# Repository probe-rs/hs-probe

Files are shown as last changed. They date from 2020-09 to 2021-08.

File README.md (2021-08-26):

# The Rusty High-speed Probe

This is an open hardware probe for the Serial Wire Debug (SWD) and JTAG protocol. It utilizes an
STM32F723 MCU which has an USB 2.0 High-speed Phy.

## Firmware

The firmware is available here and is open-source: https://github.com/probe-rs/hs-probe-firmware

## Features

There is an USB MUX on the board, so when the probe starts it enumerates in USB FS where one can
access the internal bootloader, and then when the firmware takes over it can switch to the USB HS.

* The output connector can either be:
    * The STDC14 connector used on STLink/V3 which is mounted by default.
    * Or the standard Cortex-M Debug (1.27mm, 10 pin) connector if one bends/removes the outer 2 pins on the connector.
* The programming connector is the Tag Connect TC2030, however for just loading firmware the USB bootloader is recommended.
* USB is muxed between USB HS/FS.
* Castellated vias for all programming pins, power and 2 GPIOs.
* USB-C connector.
* Target 5V and 3.3V is protected with an ideal diode circuit to not have current flow from the target to the host.
* For compatibility (mainly with Tag-Connect TC2050), pin 7 on the STDC 14 can be connected to the protected 5V.

The schematic can be found in [the schematic PDF](schematic-v1.4.pdf).

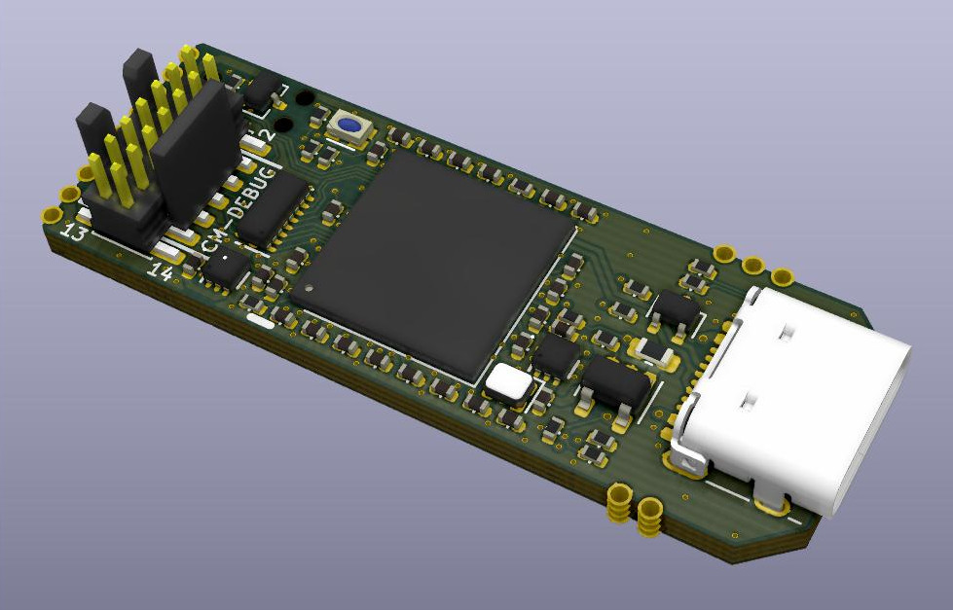
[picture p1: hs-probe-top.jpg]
probe

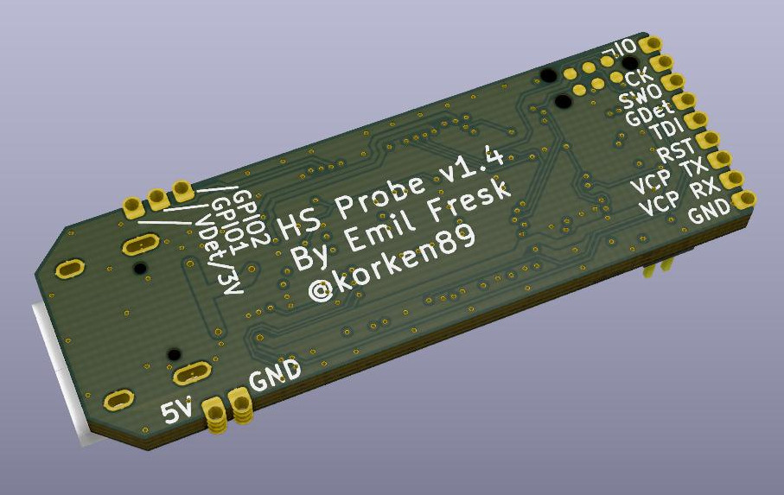
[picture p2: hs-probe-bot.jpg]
probe


## Cable Assembly

The hs-probe package sold on our [shop](https://shop.probe.rs) contains two 16 wire ribbon cables, three 14p connectors and one 10p connector.
You can make one cable with a 14p connector on each side and one cable with a 14p connector on one and a 10p connector on the other side. How to align the connectors is explained in the image below:

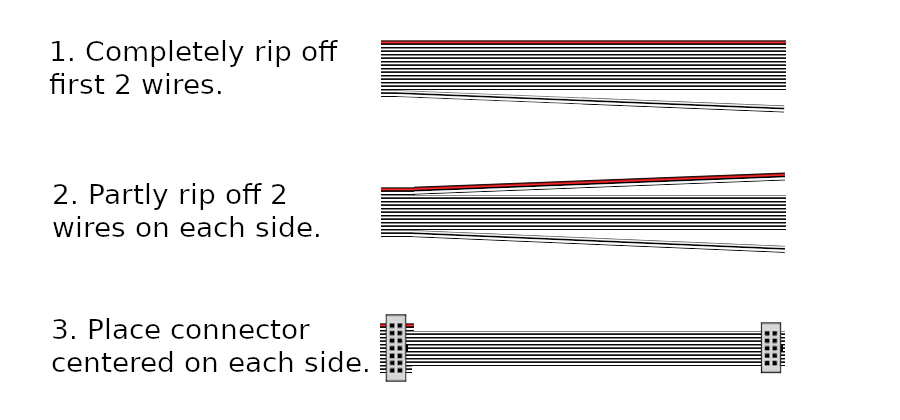
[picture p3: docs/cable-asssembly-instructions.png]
cable assembly


## License

This work is licensed under [CERN-OHL-P](cern_ohl_p_v2.txt).

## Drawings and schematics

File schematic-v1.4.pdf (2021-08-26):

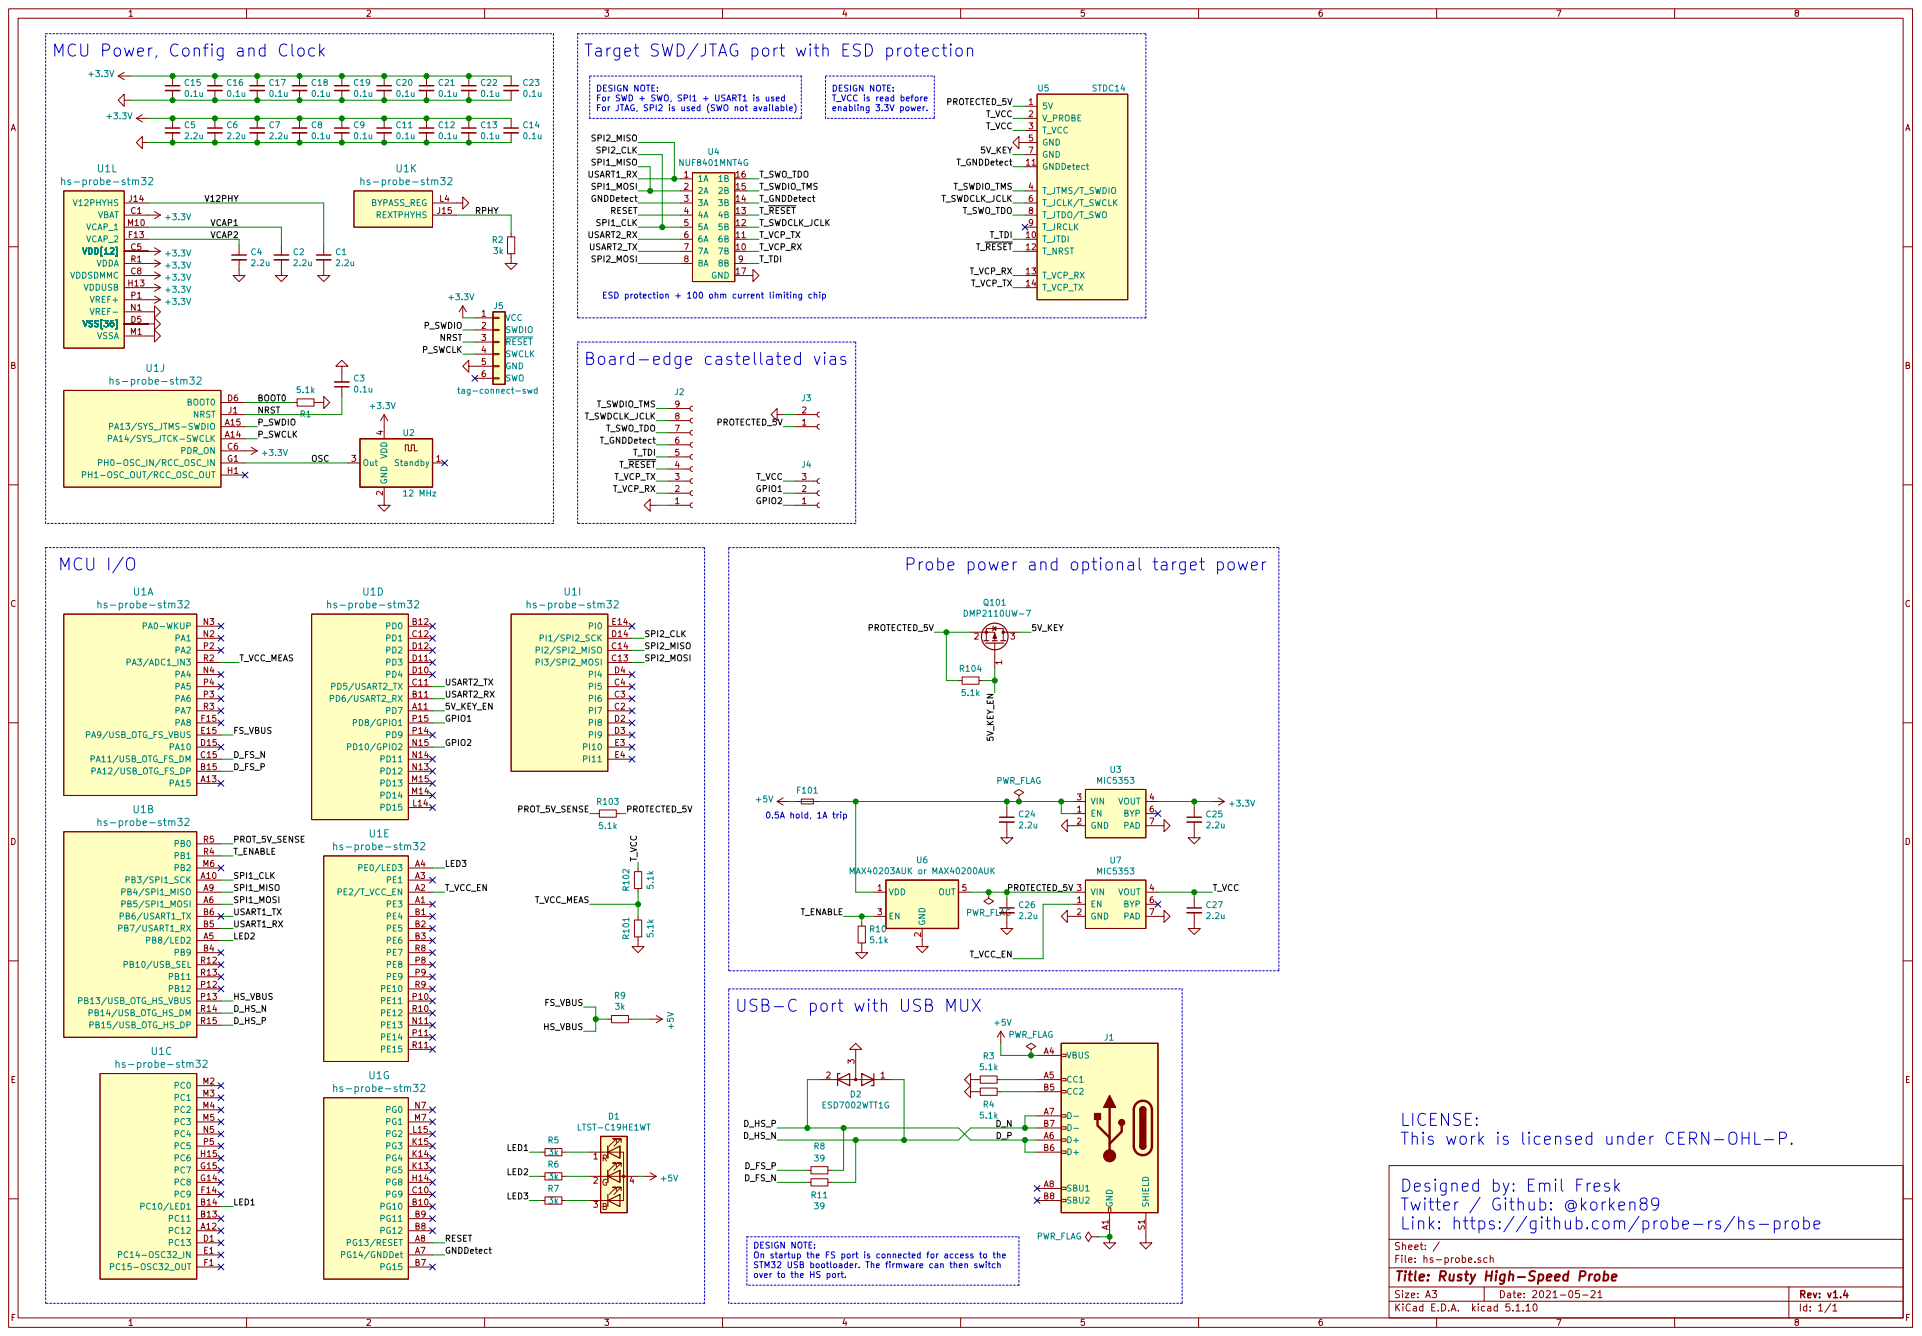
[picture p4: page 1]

MCU Power, Config and Clock

Target SWD/JTAG port with ESD protection

DESIGN NOTE: For SWD + SWO, SPI1 + USART1 is used For JTAG, SPI2 is used (SWO not available)

ESD protection + 100 ohm current limiting chip

Board-edge castellated vias

USB-C port with USB MUX

LICENSE:
This work is licensed under CERN-OHL-P.

Designed by: Emil Fresk
Twitter / Github: @korken89
Link: https://github.com/probe-rs/hs-probe

DESIGN NOTE: On startup the FS port is connected for access to the STM32 USB bootloader. The firmware can then switch over to the HS port.

File: hs-probe.sch Sheet: /
Id: 1/1 Title: Rusty High-Speed Probe

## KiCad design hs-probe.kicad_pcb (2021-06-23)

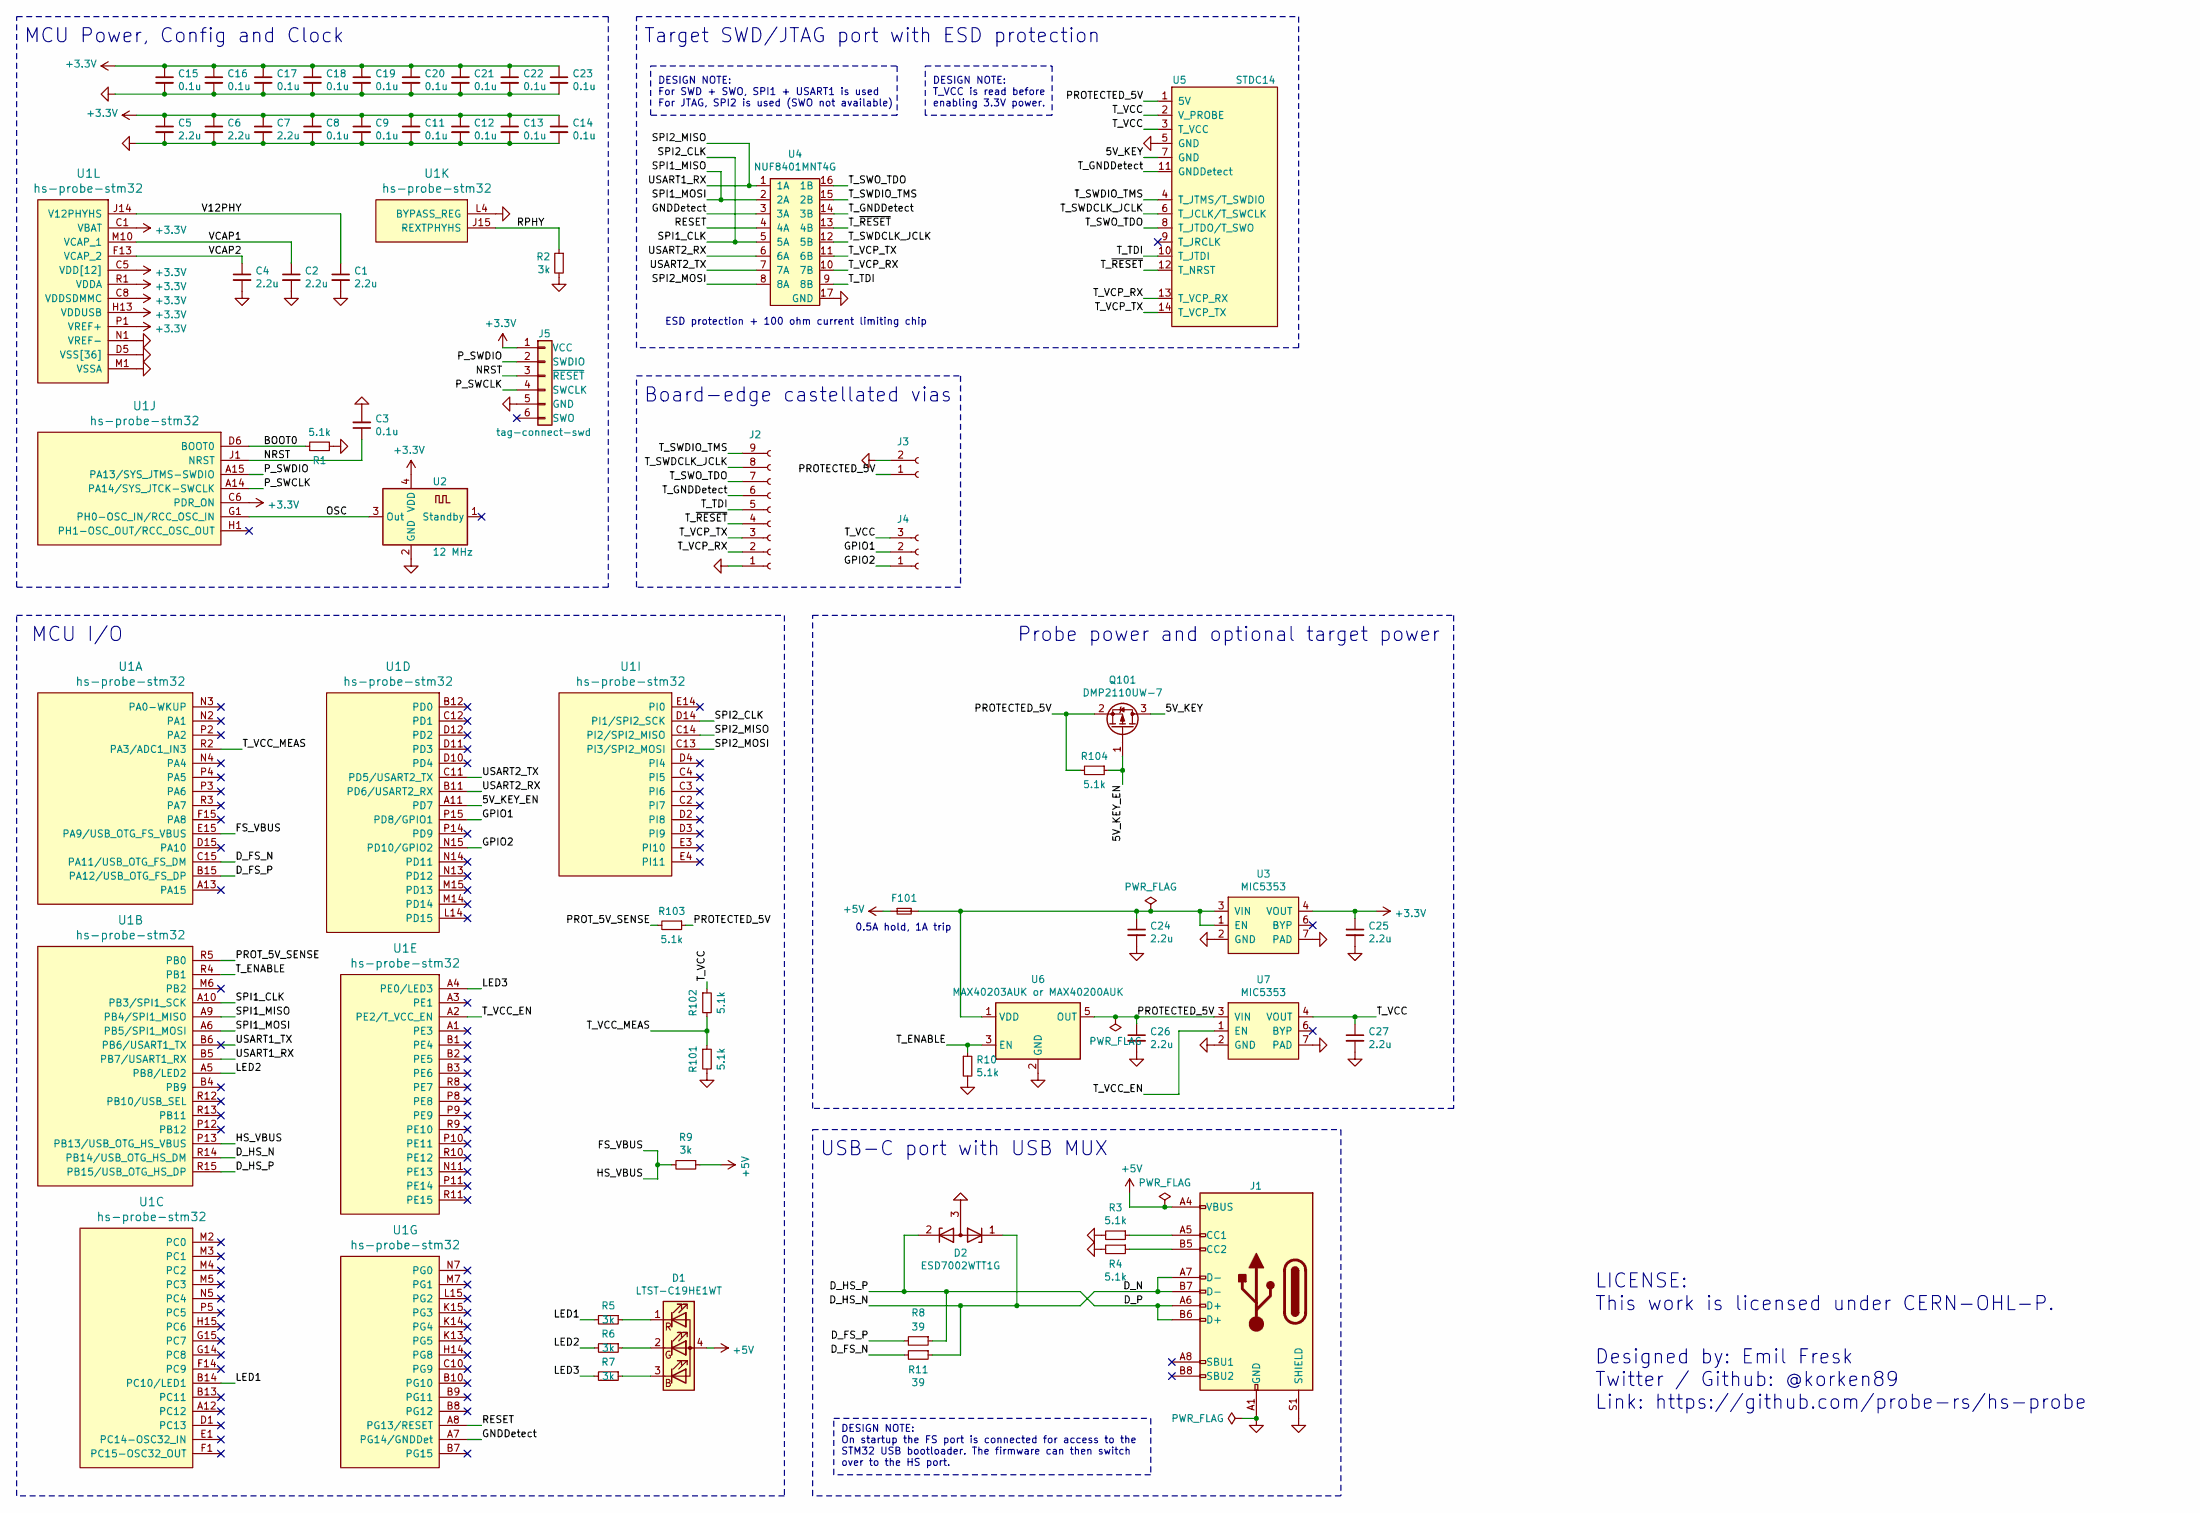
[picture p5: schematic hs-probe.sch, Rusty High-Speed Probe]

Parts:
C1, C2, C4, C5, C6, C7, C24, C25, C26, C27: 2.2u; C_0402; Tolerance 10V, X5R
C3, C8, C9, C11, C12, C13, C14, C15, C16, C17, C18, C19, C20, C21, C22, C23: 0.1u; C_0402; Tolerance 25V, X7R
D1: LTST-C19HE1WT; LED_LiteOn_LTST-C19HE1WT; MPN LTST-C19HE1WT
D2: ESD7002WTT1G; SOT-323
F101: Fuse_Small; Fuse_0603_1608Metric
J1: USB_C_Receptacle_USB2.0; USB_C_Receptacle_USB4105; MPN C167321 (lcsc.com)
J2: Castellated Vias; 1x9_1.5mm_castellated
J3: Castellated Vias; 1x2_1.5mm_castellated
J4: Castellated Vias; 1x3_1.5mm_castellated
J5: tag-connect-swd; Tag-Connect_TC2030-IDC-NL_2x03_P1.27mm_Vertical
Q101: DMP2110UW-7; SOT-323
R1, R3, R4, R10, R101, R102, R103, R104: 5.1k; R_0402; Tolerance 1%
R2, R5, R6, R7, R9: 3k; R_0402; Tolerance 1%
R8, R11: 39; R_0402; Tolerance 1%
U1: hs-probe-stm32; UFBGA-201_10x10mm_Layout15x15_P0.65mm; MPN STM32F723IEK6
U2: 12 MHz; Crystal_4Pin_2.0x1.6mm; MPN KC2016Z12.0000C15XXK
U3, U7: MIC5353; DFN-6-1EP_1.6x1.6mm_P0.5mm_EP0.5x1.26mm; MPN MIC5353-3.3YMT
U4: NUF8401MNT4G; DFN-16-1EP_1.6x4mm_P0.5mm; MPN NUF8401MNT4G
U5: STDC14; PinHeader_2x07_FTSH-107-01-L-DV-K; MPN FTSH-107-01-L-DV-K
U6: MAX40203AUK or MAX40200AUK; SOT-23-5

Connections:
+3V3: C5.1, C6.1, C7.1, C8.1, C9.1, C11.1, C12.1, C13.1, C14.1, C15.1, C16.1, C17.1, C18.1, C19.1, C20.1, C21.1, C22.1, C23.1, C25.1, J5.1 (VCC), U1.C1 (VBAT), U1.C5 (VDD[12]), U1.C6 (PDR_ON), U1.C7 (VDD[12]), U1.C8 (VDDSDMMC), U1.C9 (VDD[12]), U1.F3 (VDD[12]), U1.G3 (VDD[12]), U1.G13 (VDD[12]), U1.H13 (VDDUSB), U1.J12 (VDD[12]), U1.J13 (VDD[12]), U1.K4 (VDD[12]), U1.N8 (VDD[12]), U1.N9 (VDD[12]), U1.N10 (VDD[12]), U1.P1 (VREF+), U1.R1 (VDDA), U2.4 (VDD), U3.4 (VOUT)
+5V: D1.4 (A), F101.1, J1.A4 (VBUS), J1.A9 (VBUS), J1.B4 (VBUS), J1.B9 (VBUS), R9.1
/5V_KEY: Q101.3 (D), U5.7 (GND)
/5V_KEY_EN: Q101.1 (G), R104.1, U1.A11 (PD7)
/BOOT0: R1.1, U1.D6 (BOOT0)
/D_FS_N: R11.2, U1.C15 (PA11/USB_OTG_FS_DM)
/D_FS_P: R8.2, U1.B15 (PA12/USB_OTG_FS_DP)
/D_HS_N: D2.1 (K), J1.A7 (D-), J1.B7 (D-), R11.1, U1.R14 (PB14/USB_OTG_HS_DM)
/D_HS_P: D2.2 (K), J1.A6 (D+), J1.B6 (D+), R8.1, U1.R15 (PB15/USB_OTG_HS_DP)
/FS_VBUS: R9.2, U1.E15 (PA9/USB_OTG_FS_VBUS), U1.P13 (PB13/USB_OTG_HS_VBUS)
/GNDDetect: U1.A7 (PG14/GNDDet), U4.3 (3A)
/GPIO1: J4.2, U1.P15 (PD8/GPIO1)
/GPIO2: J4.1, U1.N15 (PD10/GPIO2)
/LED1: R5.2, U1.B14 (PC10/LED1)
/LED2: R6.2, U1.A5 (PB8/LED2)
/LED3: R7.2, U1.A4 (PE0/LED3)
/NRST: C3.1, J5.3 (~RESET), U1.J1 (NRST)
/OSC: U1.G1 (PH0-OSC_IN/RCC_OSC_IN), U2.3 (Out)
/PROTECTED_5V: C26.1, J3.1, Q101.2 (S), R103.1, R104.2, U5.1 (5V), U6.5 (OUT), U7.3 (VIN)
/PROT_5V_SENSE: R103.2, U1.R5 (PB0)
/P_SWCLK: J5.4 (SWCLK), U1.A14 (PA14/SYS_JTCK-SWCLK)
/P_SWDIO: J5.2 (SWDIO), U1.A15 (PA13/SYS_JTMS-SWDIO)
/RESET: U1.A8 (PG13/RESET), U4.4 (4A)
/RPHY: R2.1, U1.J15 (REXTPHYHS)
/SPI1_CLK: U1.A10 (PB3/SPI1_SCK), U1.D14 (PI1/SPI2_SCK), U4.5 (5A)
/SPI1_MISO: U1.A6 (PB5/SPI1_MOSI), U1.A9 (PB4/SPI1_MISO), U4.2 (2A)
/SPI2_MISO: U1.B5 (PB7/USART1_RX), U1.C14 (PI2/SPI2_MISO), U4.1 (1A)
/SPI2_MOSI: U1.C13 (PI3/SPI2_MOSI), U4.8 (8A)
/T_ENABLE: R10.1, U1.R4 (PB1), U6.3 (EN)
/T_GNDDetect: J2.6, U4.14 (3B), U5.11 (GNDDetect)
/T_SWDCLK_JCLK: J2.8, U4.12 (5B), U5.6 (T_JCLK/T_SWCLK)
/T_SWDIO_TMS: J2.9, U4.15 (2B), U5.4 (T_JTMS/T_SWDIO)
/T_SWO_TDO: J2.7, U4.16 (1B), U5.8 (T_JTDO/T_SWO)
/T_TDI: J2.5, U4.9 (8B), U5.10 (T_JTDI)
/T_VCC: C27.1, J4.3, R102.1, U5.2 (V_PROBE), U5.3 (T_VCC), U7.4 (VOUT)
/T_VCC_EN: U1.A2 (PE2/T_VCC_EN), U7.1 (EN)
/T_VCC_MEAS: R101.1, R102.2, U1.R2 (PA3/ADC1_IN3)
/T_VCP_RX: J2.2, U4.10 (7B), U5.13 (T_VCP_RX)
/T_VCP_TX: J2.3, U4.11 (6B), U5.14 (T_VCP_TX)
/T_~RESET: J2.4, U4.13 (4B), U5.12 (T_NRST)
/USART1_TX: U1.B6 (PB6/USART1_TX)
/USART2_RX: U1.B11 (PD6/USART2_RX), U4.6 (6A)
/USART2_TX: U1.C11 (PD5/USART2_TX), U4.7 (7A)
/V12PHY: C1.1, U1.J14 (V12PHYHS)
/VCAP1: C2.1, U1.M10 (VCAP_1)
/VCAP2: C4.1, U1.F13 (VCAP_2)
GND: C1.2, C2.2, C3.2, C4.2, C5.2, C6.2, C7.2, C8.2, C9.2, C11.2, C12.2, C13.2, C14.2, C15.2, C16.2, C17.2, C18.2, C19.2, C20.2, C21.2, C22.2, C23.2, C24.2, C25.2, C26.2, C27.2, D2.3 (A), J1.A1 (GND), J1.A12 (GND), J1.B1 (GND), J1.B12 (GND), J1.S1 (SHIELD), J2.1, J3.2, J5.5 (GND), R1.2, R2.2, R3.2, R4.2, R10.2, R101.2, U1.D5 (VSS[36]), U1.D7 (VSS[36]), U1.D8 (VSS[36]), U1.D9 (VSS[36]), U1.F2 (VSS[36]), U1.F6 (VSS[36]), U1.F7 (VSS[36]), U1.F8 (VSS[36]), U1.F9 (VSS[36]), U1.F10 (VSS[36]), U1.F12 (VSS[36]), U1.G2 (VSS[36]), U1.G6 (VSS[36]), U1.G7 (VSS[36]), U1.G8 (VSS[36]), U1.G9 (VSS[36]), U1.G10 (VSS[36]), U1.G12 (VSS[36]), U1.H6 (VSS[36]), U1.H7 (VSS[36]), U1.H8 (VSS[36]), U1.H9 (VSS[36]), U1.H10 (VSS[36]), U1.H12 (VSS[36]), U1.J6 (VSS[36]), U1.J7 (VSS[36]), U1.J8 (VSS[36]), U1.J9 (VSS[36]), U1.J10 (VSS[36]), U1.K6 (VSS[36]), U1.K7 (VSS[36]), U1.K8 (VSS[36]), U1.K9 (VSS[36]), U1.K10 (VSS[36]), U1.L4 (BYPASS_REG), U1.M1 (VSSA), U1.M8 (VSS[36]), U1.M9 (VSS[36]), U1.N1 (VREF-), U2.2 (GND), U3.2 (GND), U3.7 (PAD), U4.17 (GND), U5.5 (GND), U6.2 (GND), U7.2 (GND), U7.7 (PAD)
unnamed: C24.1, F101.2, U3.1 (EN), U3.3 (VIN), U6.1 (VDD)
unnamed: D1.1 (RK), R5.1
unnamed: D1.2 (GK), R6.1
unnamed: D1.3 (BK), R7.1
unnamed: J1.A5 (CC1), R3.1
unnamed: J1.B5 (CC2), R4.1

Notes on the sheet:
USB-C port with USB MUX
DESIGN NOTE: On startup the FS port is connected for access to the STM32 USB bootloader. The firmware can then switch over to the HS port.
Board-edge castellated vias
Probe power and optional target power
MCU I/O
MCU Power, Config and Clock
Target SWD/JTAG port with ESD protection
DESIGN NOTE: T_VCC is read before enabling 3.3V power.
DESIGN NOTE: For SWD + SWO, SPI1 + USART1 is used For JTAG, SPI2 is used (SWO not available)
Designed by: Emil Fresk Twitter / Github: @korken89 Link: https://github.com/probe-rs/hs-probe
LICENSE: This work is licensed under CERN-OHL-P.
ESD protection + 100 ohm current limiting chip
0.5A hold, 1A trip

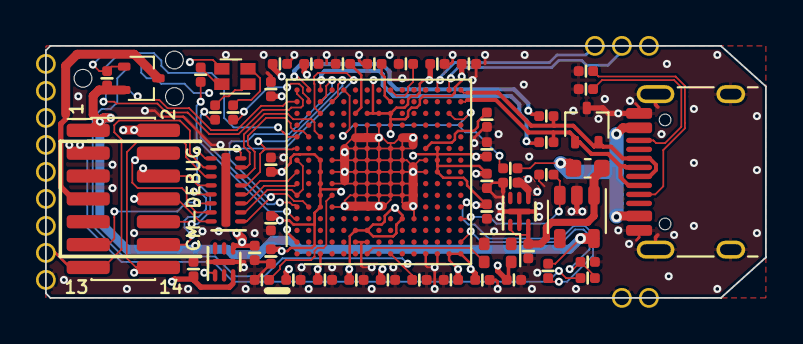
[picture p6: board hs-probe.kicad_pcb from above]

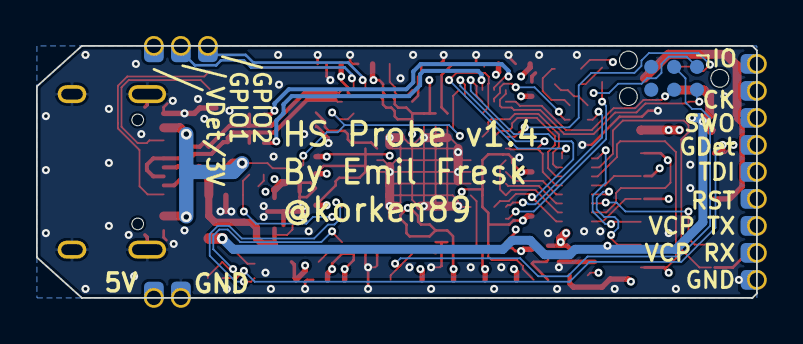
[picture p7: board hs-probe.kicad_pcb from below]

Board: 4 copper layers, 40.0 x 14.0 mm, 57 parts (4 on the bottom side), 52 nets.

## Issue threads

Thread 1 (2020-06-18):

DAPLink firmware

flit, 2020-06-18:
Very cool design! You should consider using the [DAPLink](https://github.com/ARMmbed/DAPLink) firmware. We don't yet support the F723, but it's been on the requested and we'd happily accept contributions. Other work is ongoing by a partner to support the H747.

korken89, 2020-06-19:
Hi, thanks for the kind words!

The hardware design was made with the main focus of being a reference USB 2.0 High-Speed probe for probe-rs. This does not impact support for other firmware, but unfortunately I do not have time to put currently.

If anyone in your development community is interested to get a probe for developing firmware, they can contact me and I'll send a probe to the person. :)
Plus if there is feedback on missing features or ideas they are most welcome!

Have a good day!

flit, 2020-06-19:
Understood, I'm very familiar with lack of time! Either me or a colleague will be in touch about a board soon. 😄

korken89, 2020-06-22:
Do so, it would be awesome to see more open hardware high-speed probes!

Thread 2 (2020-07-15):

ST-LINKv3 compatibility

Disasm, 2020-07-15:
As far as I can tell from different sources including the [schematics](https://raw.githubusercontent.com/RadioOperator/CMSIS-DAP_for_STLINK-V3MINI/master/STLINK-V3MINI/Sch/STLINK-V3E_Sch_from_G431sch.jpg) and STLINK-V3SET user manual, pin 1 and pin 2 of the STDC14 connector are used as power output, while pin 3 is an input to stlink.

I'd like suggest the following changes in order to improve stlink-v3 compatibility and use consistent signalling across stlinkv3 and hs-probe.
* since hs-probe has a separate power supply for 3.3V on target, it's better to connect it to pin 2 instead of pin 3.
* use pin 3 of the STDC14 connector to measure target voltage.
* optionally make pin 1 of the STDC14 connector switchable, ST uses STMPS2151STR to control it.

korken89, 2020-07-16:
This has been updated to follow, thanks for the feedback!

Closed 2020-07-16.

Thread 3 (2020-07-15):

Connect USB FS pins to the USB connector

Disasm, 2020-07-15:
We have a few reasons to use USB FS at the moment:
* Embedded DFU bootloader only supports USB FS peripheral
* Rust USB driver is not ready yet to handle USB HS

It would be great to allow the firmware to use both USB FS and HS peripherals via the same USB connector, and switch between them.
* Use USB switch (like USB3740B suggested by @korken89). Probably it's a good idea to make USB FS channel enabled by default so that the DFU bootloader can work without any knowledge about this switch.
* Use different (5V-tolerant) pins for LED2 and LED3 to not interfere with USB FS signalling.

korken89, 2020-07-16:
This has been added via USB Mux, thanks for the feedback!

Closed 2020-07-16.

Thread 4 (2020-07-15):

Castellated vias

Disasm, 2020-07-15:
It would be great to have castellated vias on the edge of the board with all the signals from the STDC14 connector and a few more. This will provide the following benefits:
* The board can be used as a module, soldered to another board
* Castellated edges themselves allow the user to hold the board tight while ejecting or inserting USB cable

korken89, 2020-07-16:
These have been added, thanks for the feedback!

Closed 2020-07-16.

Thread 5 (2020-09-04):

5V Out

dbrgn, 2020-09-04:
The JLink allows powering the target device through [pin 19 of the 20-pin connector](https://www.segger.com/products/debug-probes/j-link/technology/interface-description/) or [pin 7 of the 10-pin connector (opposite of TDI)](https://github.com/gfroerli/hardware-v2/blob/master/datasheets/ARM-JTAG-20-10_latest-schematic.pdf) (at least on the Olimex adapter. On other adapters, this pin is often unused and removed for keying). To enable this feature, you need to send the "power on" command to the debug probe first. You can chose between "power on" (temporarily enable 5V/USB power out until the probe is unplugged) or "power on perm" (permanently enable power on that pin).

It would be nice if the hs-probe would support this as well! I use that feature extensively, it saves a lot of time if I don't need a separate power supply.

korken89, 2020-09-04:
In general I see no issue with this, but the STDC14 connector has GND on the KEY pin.
One could add a dual MOSFET to switch between GND or 5V.

Right now we have followed the STLinkV3 implementation and supply 5V on pin 1 of the STDC14 connector.

korken89, 2020-11-28:
I fixed this for v1.3 :)

Closed 2020-11-28.

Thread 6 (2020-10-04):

[V1.1] It's impossible to use Tag Connect and debug connector at the same time

Disasm, 2020-10-04:
50mil debug connector head is wide and overlaps with the Tag Connect footprint.

Yatekii, 2020-10-04:
Ohh, good spot =) And yes, ofc, for writing the actual probe firmware, this is vital!

korken89, 2020-10-20:
I have updated this locally, will push a fix soon :)

korken89, 2020-10-20:
Fixed in 7cd8694384acd9bc7e83096ea85dd7931b26ae8c

Closed 2020-10-20.

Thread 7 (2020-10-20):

How to get a hs-probe?

Sympatron, 2020-10-20:
Is there any plan to produce and sell these?

The layout doesn't quite lend itself to hand soldering, which makes low volume production (especially one piece) not really feasible.

I think this project is a great idea, because it enables to use a full debugging stack written in pure open source Rust, which would be awesome!

korken89, 2020-10-20:
Hi!

Indeed there are plans! We have gotten quotes from a few manufacturers for a run of 100 probes and we are just hashing out the final design details that has come up during testing.
Exactly how it will be sold is not 100% clear right now, but it will be done somehow. :)

I will soon start a "I want one" list where people can sign up and with quantity as I will need to lay out with a (for me significant) sum of money until most probes are sold, and I'll make an order when we have enough interested.
If it does not get to enough I will most likely manufacture them myself (up to maybe 20 pcs) to increase awareness and see how demand goes from there. :)

Thanks for showing interest!

BR Emil

Sympatron, 2020-10-20:
Where do you plan to announce updates to this?

korken89, 2020-10-20:
I have planned to use the following channels:

- Probe-rs Matrix Channel
- Rust Embedded Matrix Channel
- This and the firmware repository
- Rust Embedded newsletter

korken89, 2020-10-28:
The list is up, here is a link for the one looking:
https://docs.google.com/forms/d/e/1FAIpQLScj-8rHTeytxxHBYu0chEmUiG58iWNTc8dejDOi9G5oWHEf3w/viewform

werediver, 2022-08-10:
The [shop](https://shop.probe.rs/) is currently down (reports 403 Forbidden). Are there any plans to bring it up again?

Yatekii, 2022-08-10:
The current semiconductor market is in terrible shape still, unfortunately. Which is why we cannot manufacture more of the probe, which is also why I took down the link on the page.

Closed 2022-08-10.

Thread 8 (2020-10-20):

Protect target power from backflow to host

korken89, 2020-10-20:
If the target provides a voltage higher than the hosts 5V it will now flow backwards which can cause damage.
Look into adding an ideal diode circuit with reverse current protection to combat this issue.

korken89, 2020-10-20:
Fixed in 7cd8694384acd9bc7e83096ea85dd7931b26ae8c

Closed 2020-10-20.

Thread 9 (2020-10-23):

What about an additional standard 10-pin Cortex-M debug header?

sirhcel, 2020-10-23:
Thank you for your awesome work! Today we discussed in [#probe-rs:matrix.org](https://matrix.to/#/#probe-rs:matrix.org) that having a standard 10-pin Cortex-M debug header would be a great feature for future releases if space is no concern.

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

A 14 pin cable does not fit in all cases and not eveyone has 1,27 mm cables and connectors around. These connectors could be placed directly besides each other as only one cable should be connected at a time.

sirhcel, 2020-10-23:
Wrong button ... :-|

Sympatron, 2020-10-27:
I would vote for a 14-10 cable (maybe optional) since they are easy to manufacture. Even a DIY kit (14-pin connector, 10-pin connector and a 10 pin cable) would be sufficient in my opinion.

korken89, 2020-10-27:
Hi, I have tested making a 14-10 pin cable and it went great.
So for the order I will add so one can check if they want a 14-14 cable and/or a 14-10 cable.
For the ones using tag-connect cables there is already compatible cables.

Having 2 connectors on the board is no problem technically, but the connector used on the board is 1/5 the price of the total BOM.
So I am not very keen on having 2. :)

sirhcel, 2020-10-28:
That's good news! Having the option to get an appropriate cable or its parts along with the probe solves this issue for me.

> Having 2 connectors on the board is no problem technically, but the connector used on the board is 1/5 the price of the total BOM.
> So I am not very keen on having 2. :)

I see your point and agree.

Please close this issue at your discretion.

korken89, 2020-10-28:
Glad to hear it! Closing for now.

Closed 2020-10-28.

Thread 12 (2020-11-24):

USB TTL UART Capability

dbrgn, 2020-11-24:
I'm not sure if this is possible over the shared USB port, but: When debugging a device with UART output, it would be fantastic if the hs-probe could also be used as a serial adapter via USB.

Is it possible that a USB device can be used both as a programmer/debugger, and as a separate serial adapter?

Right now I always need to plug in two cables into my computer: The JLink and a generic USB serial adapter... It would be great if those could be combined. (Yes, I'm aware of RTT, but some projects need to use UART...)

Disasm, 2020-11-24:
hs-probe for sure can be used in this way, but we don't have a firmware support yet. But this is definitely something to be implemented!

dbrgn, 2020-11-24:
Ah, awesome! :tada:

What about the hardware? The SWD pinout doesn't have serial RX/TX. But on this rendering...

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

...there are two RX/TX pins on the right side. Could those be used, given firmware support?

Maybe a dedicated 3-pin header (RX/TX/GND) could be added in a future version.

Disasm, 2020-11-24:
RX/TX signals are also available on the STDC14 connector. The ones on the board edge are the same signals.

dbrgn, 2020-11-24:
> RX/TX signals are also available on the STDC14 connector.

Ah, interesting! So far I've mostly used the 10-pin SWD connector in my projects, but that might be a reason to switch to the 14-pin connector.

> Actually, it's already present in firmware and available to your host system, but all the data comes directly into the void.

@Yatekii I'm very much looking forward to the first hardware prototypes, I might give this a try :slightly_smiling_face:

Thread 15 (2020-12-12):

Using hs-probe in non rust projects.

C47D, 2020-12-12:
Hi,
I didn't searched a lot, is it possible to use this probe in non rust projects? Just signed up on the mailing list!

Yatekii, 2020-12-12:
Hi!

Yes, this is 100% possible. We implement the CMSIS-DAP specification which is an open standard by ARM intended for SWD & J-Tag debugging.
So this probe will also work with Keil for example.

Great to hear!

C47D, 2020-12-14:
Thanks for the information, looking forward to get an hs-probe!

Closed 2020-12-14.

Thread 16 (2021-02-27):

Allow for different VDD_Target

allexoll, 2021-02-27:
In the current version the probe allows for 3v3 and 5v, it might be interesting to add 1v8 functionality.

If we want it to exclusively work with 1v8, that could be done by just switching the MIC5353-3.3YMT for a MIC5353-1.8YMT and the STM32F723 supports it.
But if we need a range of functionality (most of segger's [probes](https://www.segger.com/products/debug-probes/j-link/models/model-overview/) do 1.2v -> 5V) , that might require something more complex.

allexoll, 2021-05-21:
I think what is usually done  is using VDD_TARGET to power the target side of a level translator.

korken89, 2021-05-21:
The main issue with level translators is that they need to be bidirectional, and with that often come with problematic special cases.
So personally I'm not in favor of a level translator approach.

What one could do though is to let the MCU set the resistor divider and control it's voltage in the range 1.8 - 3.3v.

allexoll, 2021-07-13:
at least for SWD that's doable ie: NXP's LPC55S16-EVK

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

What kind of edge case were you thinking about?

having a resistor div for the LDO would be doable, but you're limited to the vdd range of the probe's MCU (ie: no 5V target)

i'm unsure how segger or ST do it

diggit, 2022-04-11:
This is the only reason keeping me from using hs-probe. Are then any plans?
I am also willing t help with HW development if there is agreed solution.

allexoll, 2022-04-11:
@korken89 has been working on a new [rp2040 probe](https://github.com/probe-rs/rusty-probe), which includes adjustable signaling, you should look that up

Closed 2022-04-11.

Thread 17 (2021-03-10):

Create a release?

thejpster, 2021-03-10:
Would it be possible to create some releases in Github, containing the rendered schematics and gerbers? I think this would more easily allow people to track the revisions of the PCB, without the git repository spiralling in size due to lots of PDFs being uploaded.

You can even use Github Actions to create the PDFs and the Gerbers. See https://github.com/Neotron-Compute/Neotron-Baseboard-100/blob/develop/.github/workflows/kicad-release.yml for a basic example.

Yatekii, 2021-03-10:
Yes, this is something we have on the todo :) I just didn't get around to do this yet. Thanks for making an issue :)

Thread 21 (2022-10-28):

Add a level shifter for logic signals

DSTkrt, 2022-10-28:
If the target core is supplied with a voltage other than 3.3V, driving a signal line high will forward-bias the target pins esd diode, which may be destructive.
Segger solves this in their J-Link by having a level shifter between their microcontroller and the target core. ST doesn't care and blasts 3.3V on the core anyways.

I'd suggest adding a bi-directional level shifter behind the ESD protection IC. Proper care needs to be taken when selecting the IC, since they are limited in silly ways. For example:
* [NLSX4014](https://www.onsemi.com/pdf/datasheet/nlsx4014-d.pdf) has stupid restrictions on power supplies (as many others do), namely VCCB < VCCA-0.4V
* [PI4ULS3V204](https://www.diodes.com/assets/Datasheets/PI4ULS3V204.pdf) is too slow.

Alternatively, an unidirectional with direction control might do, too, the firmware will need to manage the direction of the translation, then...

adamgreig, 2022-11-03:
It's not likely any more hs-probe will be made soon due to parts shortages, but there has been work on a new probe [here (rusty-probe)](https://github.com/probe-rs/rusty-probe) which does include level-shifters for 1.8-3.3v.

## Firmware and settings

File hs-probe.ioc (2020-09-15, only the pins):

PH0-OSC_IN.Signal=RCC_OSC_IN
Mcu.UserName=STM32F723IEKx
PC10.Signal=GPIO_Output
PB13.Signal=USB_OTG_HS_VBUS
PB15.Signal=USB_OTG_HS_DP
PG13.Signal=GPIO_Output
PA12.Signal=USB_OTG_FS_DP
PB6.Signal=USART1_TX
PD8.Signal=GPIO_Output
PI3.Signal=SPI2_MOSI
PE2.Signal=GPIO_Output
PB7.Signal=USART1_RX
PE0.GPIO_Label=LED3
PD6.Signal=USART2_RX
PE2.GPIO_Label=T_VCC_EN
PB4.Signal=SPI1_MISO
PA3.Signal=ADCx_IN3
PC10.GPIO_Label=LED1
PD5.Signal=USART2_TX
PG13.GPIO_Label=RESET
PD8.GPIO_Label=GPIO1
PD10.Signal=GPIO_Output
PA13.Signal=SYS_JTMS-SWDIO
PB8.GPIO_Label=LED2
PB10.GPIO_Label=USB_SEL
PA9.Signal=USB_OTG_FS_VBUS
PD10.GPIO_Label=GPIO2
PB10.Signal=GPIO_Output
PB14.Signal=USB_OTG_HS_DM
PG14.Signal=GPIO_Output
PI2.Signal=SPI2_MISO
PI1.Signal=SPI2_SCK
PH1-OSC_OUT.Signal=RCC_OSC_OUT
PG14.GPIO_Label=GNDDet
PE0.Signal=GPIO_Output
PB3.Signal=SPI1_SCK
PB5.Signal=SPI1_MOSI
PA11.Signal=USB_OTG_FS_DM
PA14.Signal=SYS_JTCK-SWCLK
PB8.Signal=GPIO_Output

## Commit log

2020-03-31 Added missing keep-out under MCU
    [hs-probe.kicad_pcb]
2020-03-31 Fixes on STDC14 connector, fixed component courtyards
    [hs-probe.kicad_pcb, hs-probe.sch]
2020-03-31 Silkscreen cleanup
    [hs-probe.kicad_pcb]
2020-03-31 Added JTAG on SPI2
    [hs-probe.kicad_pcb, hs-probe.sch]
2020-04-01 Minor updates
    [hs-probe.kicad_pcb, hs-probe.sch]
2020-04-01 Shorted SPI1 MISO/MOSI, rotated connector
    [hs-probe.kicad_pcb, hs-probe.sch]
2020-04-06 Added ESD protection, fixed silkscreen
    [hs-probe.kicad_pcb, hs-probe.sch]
2020-04-14 Updated LED for a more commonly available one
    [hs-probe.kicad_pcb, hs-probe.sch]
2020-05-21 Fix errors
    [hs-probe.kicad_pcb, hs-probe.sch]
2020-07-15 Added USB Mux to start with FS and then switch to HS
    [hs-probe.kicad_pcb, hs-probe.sch]
2020-07-16 Updated BOM
    [hs-probe.sch]
2020-07-16 Added Castellated Vias
    [hs-probe.kicad_pcb, hs-probe.sch]
2020-07-16 Added 2 GPIO to headers
    [hs-probe.kicad_pcb, hs-probe.sch]
2020-07-16 Rotated castellated vias the right way
    [hs-probe.kicad_pcb, hs-probe.sch]
2020-07-17 Minor PCB cleanup, more GND vias
    [hs-probe.kicad_pcb]
2020-07-19 Updated design from review comment
    [hs-probe.kicad_pcb, hs-probe.sch]
2020-07-19 Major schematic cleanup
    [hs-probe.kicad_pcb, hs-probe.sch]
2020-07-19 Updated README, images and added schematic PDF
2020-07-19 Moved to tag connect
    [hs-probe.kicad_pcb, hs-probe.sch]
2020-07-19 Fixed ERC warnings
    [hs-probe.sch]
2020-07-19 Added license, dimensions and manufacturing specs
    [hs-probe.kicad_pcb, hs-probe.sch]
2020-07-19 Updated 3D models to FTSH-107-01-L-DV-K
    [hs-probe.kicad_pcb, hs-probe.sch]
2020-07-19 Improved ESD protection + current limiting clarity
    [hs-probe.sch]
2020-07-20 Thickened up power traces under MCU
    [hs-probe.kicad_pcb]
2020-08-06 Now using a 2x1.6mm crystal
    [hs-probe.kicad_pcb, hs-probe.sch]
2020-09-04 Updated crystal footprint
    [hs-probe.kicad_pcb]
2020-09-15 Updated README and minor HW cleanup
    [hs-probe.kicad_pcb]
2020-10-04 Moved to 3k resistors for the LEDs and USB detect
    [hs-probe.kicad_pcb, hs-probe.sch]
2020-10-20 Added ideal diode to target power, fixed programming connector
    [hs-probe.kicad_pcb, hs-probe.sch]
2020-10-20 Added missing pull-down resistor on ideal diode
    [hs-probe.kicad_pcb, hs-probe.sch]
2020-10-20 Resistor name update
    [hs-probe.sch]
2020-11-06 Small fixes
    [hs-probe.kicad_pcb]
2020-11-18 Added 5V target sense line
    [hs-probe.kicad_pcb, hs-probe.sch]
2020-11-28 v1.3, now can connect 5V to pin 7 of STDC14
    [hs-probe.kicad_pcb, hs-probe.sch]
2020-11-28 Changed ferrite bead for fuse
    [hs-probe.kicad_pcb, hs-probe.sch]
2021-06-23 v1.4, now without the USB mux
    [hs-probe.kicad_pcb, hs-probe.sch]
2021-08-24 Add assembly instructions
2021-08-26 v1.4 schematic, README, and images
